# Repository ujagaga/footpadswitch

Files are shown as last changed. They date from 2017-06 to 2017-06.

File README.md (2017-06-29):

# footpadswitch
Foot pad configurable shortcut key

The intention is to build a radio frequency foot switch to activate a usb device 
which acts as a HID keyboard sending an alt/F12 key code. This can be caught by an 
application which can be configured for various tasks.
I used an RF transmit module for the foot pad controller and RF receive module for
activating a microcontroller to send the key code.
The microcontroller is AtTiny2313 and the firmware is baces on AVR USB library.

The RF receiver gets a lot of noise, so I filtered it out with an RC low pass filter.
Because of this, the controlling signal must last at least 10ms.   

I wrote the application in python, built it into a standalone windows application using py2exe
and created an installer using CreateInstall. You should start the app as an administrator to 
allow writing the config file or install somewhere you have write priviledges like user 
application folder. Once you start the app, it saves current mouse position after you press 
ctrl/F12 and uses it as location to simulate a click when it receives alt/F12. This basically 
gives you the option to generate a mouse click on a configured place on the screen. I use it 
for an application which has no keyboard shortcuts and my hands are busy, so I can not click myself.

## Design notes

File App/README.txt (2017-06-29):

Footpad Switch

The application is intended to be used with a hardware radio frequency foot switch to activate 
a usb device which acts as a HID keyboard sending an alt/F12 key code. 
If you install the app in Program Files folder, you should start the app as an administrator to 
allow writing the config file or install somewhere you have write priviledges.
Once you start the app, it saves current mouse position after you press ctrl/F12 and uses it as 
location to simulate a click after detecting alt/F12. This means that to configure a place on the
screen where to simulate mouse click, place your mouse cursor and hit ctrl/F12. After that, 
to simulate mouse click, just press the footpad which will send alt/F12.

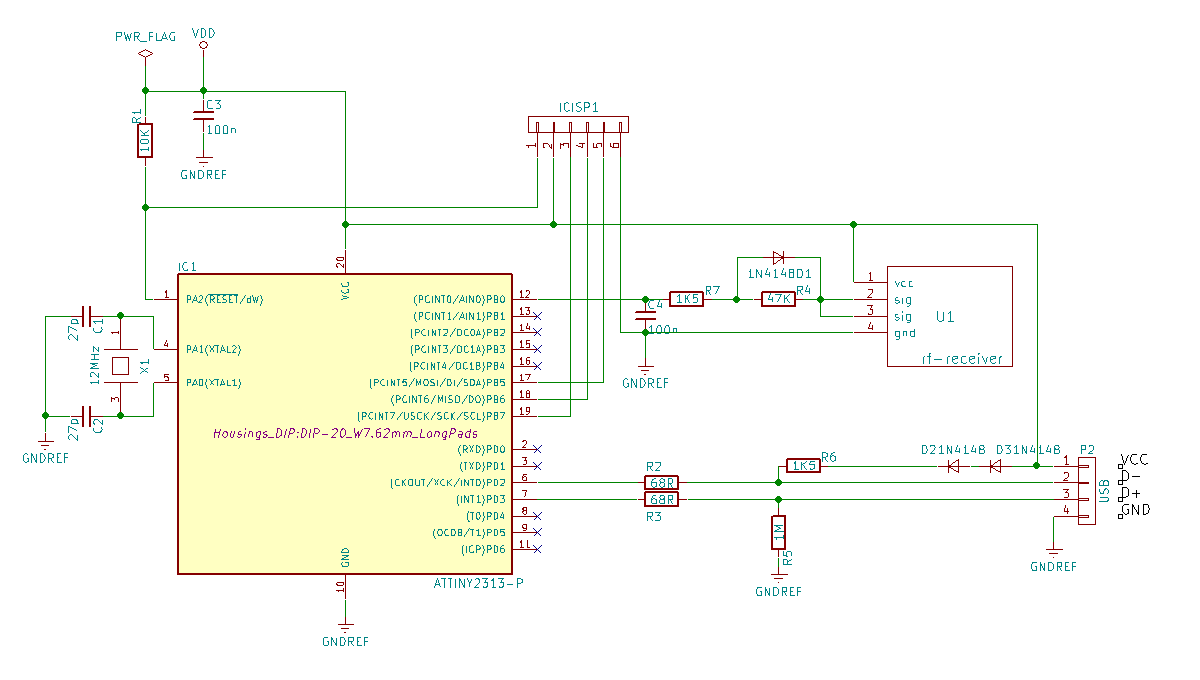
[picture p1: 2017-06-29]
PCB/wififp_receiver/SCHEMATIC.png

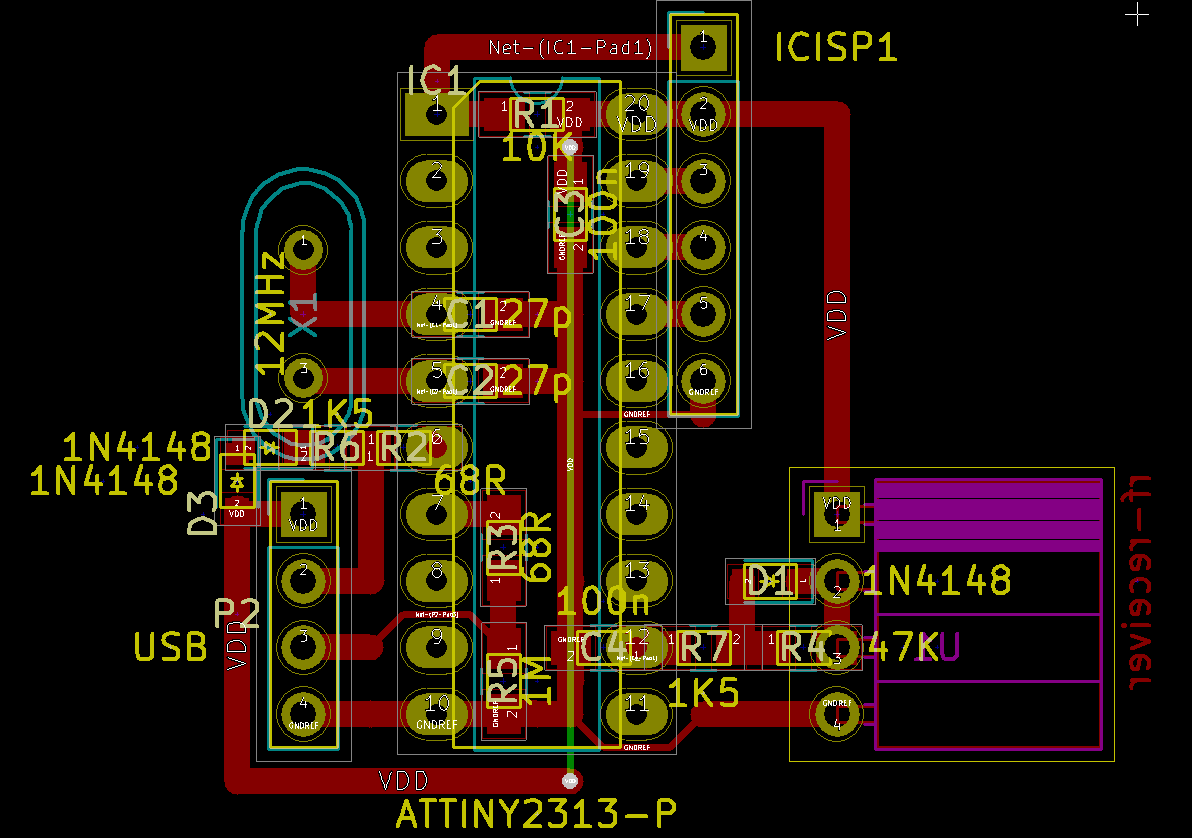
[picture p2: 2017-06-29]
PCB/wififp_receiver/PCB.png

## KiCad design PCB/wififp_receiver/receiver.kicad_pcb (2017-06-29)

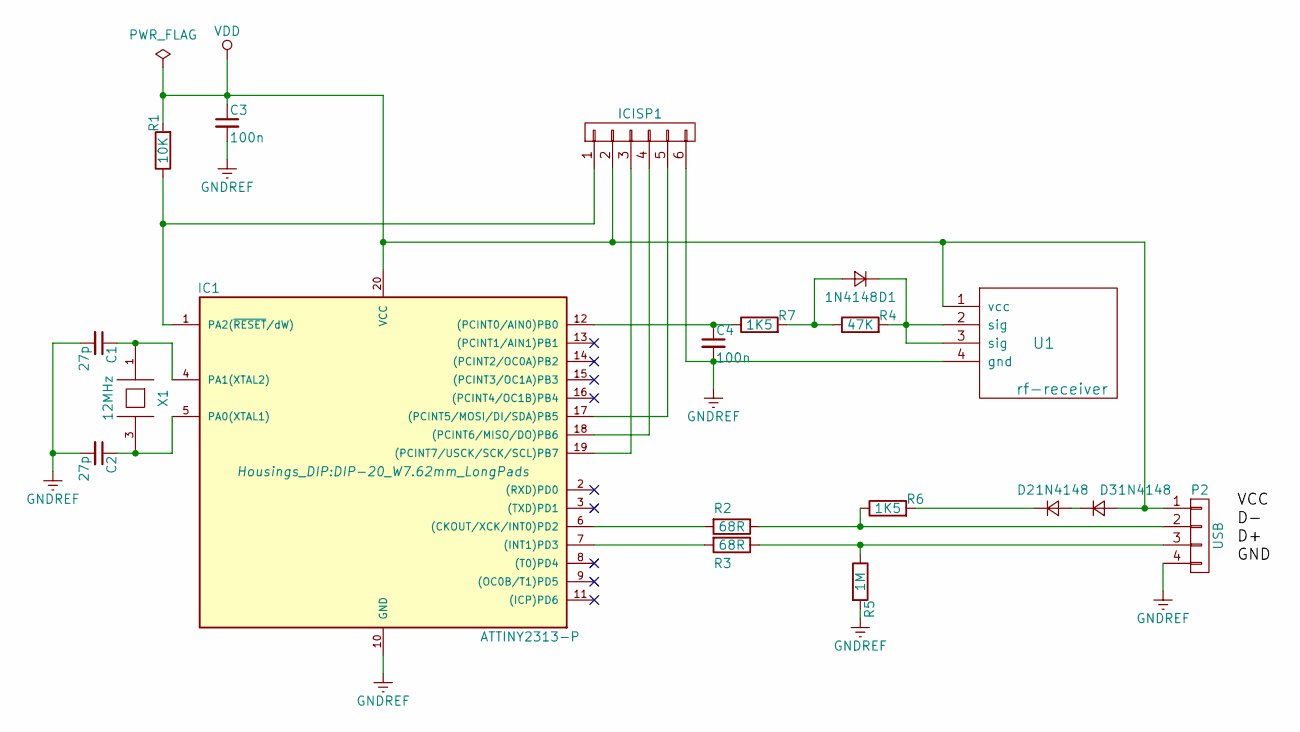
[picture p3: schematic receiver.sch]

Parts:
C1, C2: 27p; C_0805_HandSoldering
C3, C4: 100n; C_0805_HandSoldering
D1, D2, D3: 1N4148; D_0805
IC1: ATTINY2313-P; DIP-20_W7.62mm_LongPads
P1: ICISP1; Socket_Strip_Straight_1x06_Pitch2.54mm
P2: USB; Socket_Strip_Straight_1x04_Pitch2.54mm
R1: 10K; C_0805_HandSoldering
R2, R3: 68R; C_0805_HandSoldering
R4: 47K; C_0805_HandSoldering
R5: 1M; C_0805_HandSoldering
R6, R7: 1K5; C_0805_HandSoldering
U1: rf-receiver; Socket_Strip_Angled_1x04_Pitch2.54mm
X1: 12MHz; Crystal_HC49-U_Vertical

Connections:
GNDREF: C1.2, C2.2, C3.2, C4.2, IC1.10 (GND), P1.6, P2.4, R5.2, U1.4 (gnd)
unnamed: C1.1, IC1.4 (PA1(XTAL2)), X1.1
unnamed: C2.1, IC1.5 (PA0(XTAL1)), X1.3
unnamed: C4.1, IC1.12 ((PCINT0/AIN0)PB0), R7.1
unnamed: D1.1 (K), R4.2, U1.2 (sig), U1.3 (sig)
unnamed: D1.2 (A), R4.1, R7.2
unnamed: D2.1 (K), R6.2
unnamed: D2.2 (A), D3.1 (K)
unnamed: IC1.1 (PA2(~RESET~/dW)), P1.1, R1.1
unnamed: IC1.6 ((CKOUT/XCK/INT0)PD2), R2.2
unnamed: IC1.7 ((INT1)PD3), R3.2
unnamed: IC1.17 ((PCINT5/MOSI/DI/SDA)PB5), P1.5
unnamed: IC1.18 ((PCINT6/MISO/DO)PB6), P1.4
unnamed: IC1.19 ((PCINT7/USCK/SCK/SCL)PB7), P1.3
unnamed: P2.2, R2.1, R6.1
unnamed: P2.3, R3.1, R5.1
VDD: C3.1, D3.2 (A), IC1.20 (VCC), P1.2, P2.1, R1.2, U1.1 (vcc)

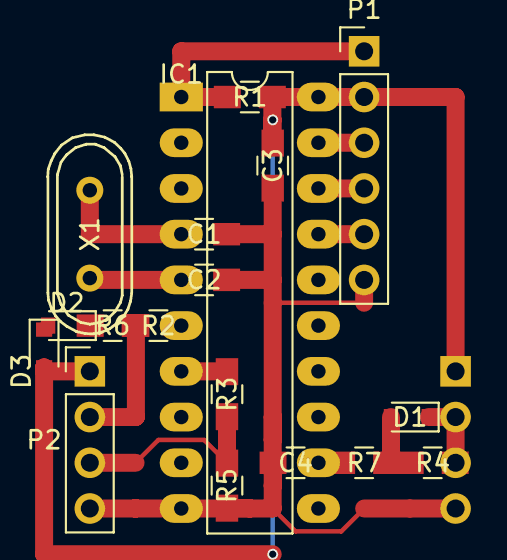
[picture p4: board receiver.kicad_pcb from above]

Board: 2 copper layers, 19 parts (1 on the bottom side), 17 nets.

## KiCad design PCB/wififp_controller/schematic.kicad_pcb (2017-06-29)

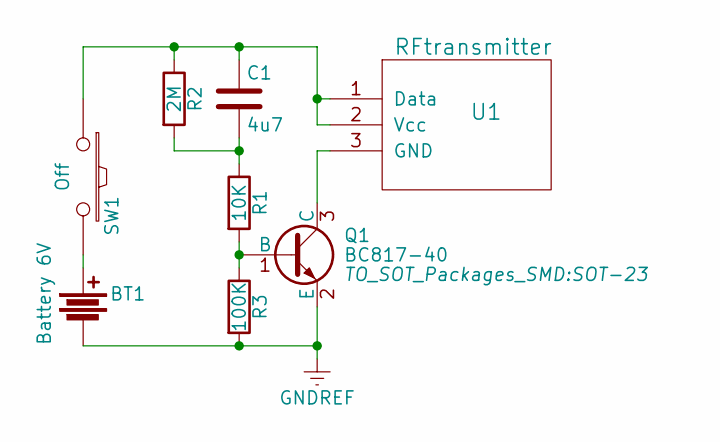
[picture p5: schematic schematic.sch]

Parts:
BT1: Battery 6V; 6V_battery_4LR44
C1: 4u7; C_0805_HandSoldering
Q1: BC817-40; SOT-23
R1: 10K; R_0805_HandSoldering
R2: 2M; R_0805_HandSoldering
R3: 100K; R_0805_HandSoldering
SW1: Off; Socket_Strip_Straight_1x02_Pitch2.54mm
U1: RFtransmitter; Socket_Strip_Angled_1x03_Pitch2.54mm

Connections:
GNDREF: BT1.2, Q1.2 (E), R3.2
unnamed: BT1.1, SW1.2
unnamed: C1.1, R2.1, SW1.1, U1.1 (Data), U1.2 (Vcc)
unnamed: C1.2, R1.1, R2.2
unnamed: Q1.1 (B), R1.2, R3.1
unnamed: Q1.3 (C), U1.3 (GND)

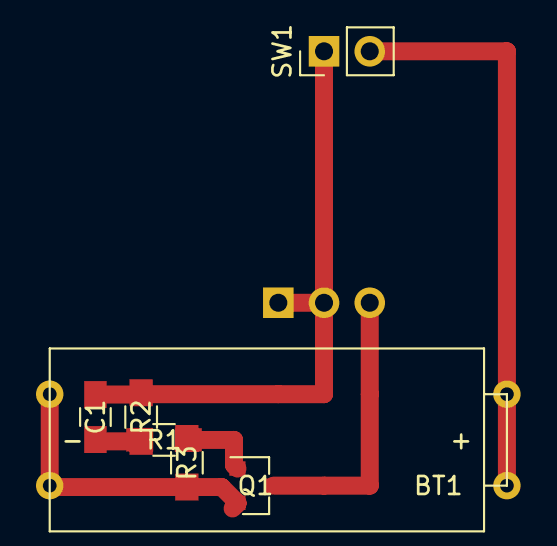
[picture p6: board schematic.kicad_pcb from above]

Board: 2 copper layers, 8 parts (1 on the bottom side), 6 nets.

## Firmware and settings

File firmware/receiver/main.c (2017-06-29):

/* Name: main.c
 * Project: hid-mouse, a very simple HID example
 * Author: Christian Starkjohann
 * Creation Date: 2008-04-07
 * Tabsize: 4
 * Copyright: (c) 2008 by OBJECTIVE DEVELOPMENT Software GmbH
 * License: GNU GPL v2 (see License.txt), GNU GPL v3 or proprietary (CommercialLicense.txt)
 */

/*
This example should run on most AVRs with only little changes. No special
hardware resources except INT0 are used. You may have to change usbconfig.h for
different I/O pins for USB. Please note that USB D+ must be the INT0 pin, or
at least be connected to INT0 as well.

We use VID/PID 0x046D/0xC00E which is taken from a Logitech mouse. Don't
publish any hardware using these IDs! This is for demonstration only!
*/

#include <avr/io.h>
#include <avr/wdt.h>
#include <avr/interrupt.h>  /* for sei() */
#include <avr/pgmspace.h>   /* required by usbdrv.h */
#include <util/delay.h>     /* for _delay_ms() */
#include <stdint.h>
#include <stdbool.h>
#include "usbdrv/usbdrv.h"

/* ------------------------------------------------------------------------- */

#define SENS_PIN			(PB0)
#define GET_STATE()			((PINB >> SENS_PIN) & 1U)
#define SENS_THREASHOLD		(10000U)

/* ----------------------------- USB interface ----------------------------- */

/* Keyboard usage values, see usb.org's HID-usage-tables document, chapter
 * 10 Keyboard/Keypad Page for more codes.
 */
#define MOD_CONTROL_LEFT    (1<<0)
#define MOD_SHIFT_LEFT      (1<<1)
#define MOD_ALT_LEFT        (1<<2)
#define MOD_GUI_LEFT        (1<<3)
#define MOD_CONTROL_RIGHT   (1<<4)
#define MOD_SHIFT_RIGHT     (1<<5)
#define MOD_ALT_RIGHT       (1<<6)
#define MOD_GUI_RIGHT       (1<<7)

#define KEY_A       4
#define KEY_B       5
#define KEY_C       6
#define KEY_D       7
#define KEY_E       8
#define KEY_F       9
#define KEY_G       10
#define KEY_H       11
#define KEY_I       12
#define KEY_J       13
#define KEY_K       14
#define KEY_L       15
#define KEY_M       16
#define KEY_N       17
#define KEY_O       18
#define KEY_P       19
#define KEY_Q       20
#define KEY_R       21
#define KEY_S       22
#define KEY_T       23
#define KEY_U       24
#define KEY_V       25
#define KEY_W       26
#define KEY_X       27
#define KEY_Y       28
#define KEY_Z       29
#define KEY_1       30
#define KEY_2       31
#define KEY_3       32
#define KEY_4       33
#define KEY_5       34
#define KEY_6       35
#define KEY_7       36
#define KEY_8       37
#define KEY_9       38
#define KEY_0       39

#define KEY_F1      58
#define KEY_F2      59
#define KEY_F3      60
#define KEY_F4      61
#define KEY_F5      62
#define KEY_F6      63
#define KEY_F7      64
#define KEY_F8      65
#define KEY_F9      66
#define KEY_F10     67
#define KEY_F11     68
#define KEY_F12     69
#define KEY_F13     70
#define KEY_F14     71
#define KEY_F15     72
#define KEY_F16     73

/* ------------------------------------------------------------------------ */

/* ------------------------------------------------------------------------- */

static uchar    pressKeyBuffer[2] = {MOD_ALT_LEFT, KEY_F12};    /* buffer for HID reports */
static uchar    releaseKeyBuffer[2] = {0, 0};    /* buffer for HID reports */
static uchar    idleRate;           /* in 4 ms units */

const PROGMEM char usbHidReportDescriptor[35] = {   /* USB report descriptor */
    0x05, 0x01,                    // USAGE_PAGE (Generic Desktop)
    0x09, 0x06,                    // USAGE (Keyboard)
    0xa1, 0x01,                    // COLLECTION (Application)
    0x05, 0x07,                    //   USAGE_PAGE (Keyboard)
    0x19, 0xe0,                    //   USAGE_MINIMUM (Keyboard LeftControl)
    0x29, 0xe7,                    //   USAGE_MAXIMUM (Keyboard Right GUI)
    0x15, 0x00,                    //   LOGICAL_MINIMUM (0)
    0x25, 0x01,                    //   LOGICAL_MAXIMUM (1)
    0x75, 0x01,                    //   REPORT_SIZE (1)
    0x95, 0x08,                    //   REPORT_COUNT (8)
    0x81, 0x02,                    //   INPUT (Data,Var,Abs)
    0x95, 0x01,                    //   REPORT_COUNT (1)
    0x75, 0x08,                    //   REPORT_SIZE (8)
    0x25, 0x65,                    //   LOGICAL_MAXIMUM (101)
    0x19, 0x00,                    //   USAGE_MINIMUM (Reserved (no event indicated))
    0x29, 0x65,                    //   USAGE_MAXIMUM (Keyboard Application)
    0x81, 0x00,                    //   INPUT (Data,Ary,Abs)
    0xc0                           // END_COLLECTION
};
/* We use a simplifed keyboard report descriptor which does not support the
 * boot protocol. We don't allow setting status LEDs and we only allow one
 * simultaneous key press (except modifiers). We can therefore use short
 * 2 byte input reports.
 * The report descriptor has been created with usb.org's "HID Descriptor Tool"
 * which can be downloaded from http://www.usb.org/developers/hidpage/.
 * Redundant entries (such as LOGICAL_MINIMUM and USAGE_PAGE) have been omitted
 * for the second INPUT item.
 */

usbMsgLen_t usbFunctionSetup(uchar data[8]){

	usbRequest_t    *rq = (void *)data;

	    usbMsgPtr = pressKeyBuffer;
	    if((rq->bmRequestType & USBRQ_TYPE_MASK) == USBRQ_TYPE_CLASS){    /* class request type */
	        if(rq->bRequest == USBRQ_HID_GET_REPORT){  /* wValue: ReportType (highbyte), ReportID (lowbyte) */
	            /* we only have one report type, so don't look at wValue */
	            return sizeof(pressKeyBuffer);
	        }else if(rq->bRequest == USBRQ_HID_GET_IDLE){
	            usbMsgPtr = &idleRate;
	            return 1;
	        }else if(rq->bRequest == USBRQ_HID_SET_IDLE){
	            idleRate = rq->wValue.bytes[1];
	        }
	    }else{
	        /* no vendor specific requests implemented */
	    }
		return 0;
}


void sendKey( void ){
	bool finished = false;
	bool keySent = false;

	while(!finished){
		wdt_reset();
		usbPoll();

		if(usbInterruptIsReady()){
			if(!keySent){
				usbSetInterrupt(pressKeyBuffer, sizeof(pressKeyBuffer));
				keySent = true;
			}else{
				usbSetInterrupt(releaseKeyBuffer, sizeof(releaseKeyBuffer));
				finished = true;
			}
		}
	}
}

void delayLoop( void ){
	volatile uint8_t i;

	for(i = 0; i < 200; i++){

		wdt_reset();
		usbPoll();

		_delay_ms(5);
	}
}


int main(void)
{
	uint16_t i = 0;

    wdt_enable(WDTO_2S);
    /* If you don't use the watchdog, replace the call above with a wdt_disable().
     * On newer devices, the status of the watchdog (on/off, period) is PRESERVED
     * OVER RESET!
     */
    /* RESET status: all port bits are inputs without pull-up.
     * That's the way we need D+ and D-. Therefore we don't need any
     * additional hardware initialization.
     */
    usbInit();
    usbDeviceDisconnect();  /* enforce re-enumeration, do this while interrupts are disabled! */

    i = 255;
    while(--i){             /* fake USB disconnect for > 250 ms */
        wdt_reset();
        _delay_ms(1);
    }
    usbDeviceConnect();
    sei();

    for(;;){                /* main event loop */
        wdt_reset();
        usbPoll();

        if(GET_STATE()){	/* test if command requested */
        	i++;
        }else{
        	i = 0;
        }

        if( i == SENS_THREASHOLD){
        	sendKey();
        	i = 0;
        	delayLoop();
        }
    }

    return 0;
}

/* ------------------------------------------------------------------------- */

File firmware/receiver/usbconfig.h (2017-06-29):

/* Name: usbconfig.h
 * Project: V-USB, virtual USB port for Atmel's(r) AVR(r) microcontrollers
 * Author: Christian Starkjohann
 * Creation Date: 2005-04-01
 * Tabsize: 4
 * Copyright: (c) 2005 by OBJECTIVE DEVELOPMENT Software GmbH
 * License: GNU GPL v2 (see License.txt), GNU GPL v3 or proprietary (CommercialLicense.txt)
 */

#ifndef __usbconfig_h_included__
#define __usbconfig_h_included__

/*
General Description:
This file is an example configuration (with inline documentation) for the USB
driver. It configures V-USB for USB D+ connected to Port D bit 2 (which is
also hardware interrupt 0 on many devices) and USB D- to Port D bit 4. You may
wire the lines to any other port, as long as D+ is also wired to INT0 (or any
other hardware interrupt, as long as it is the highest level interrupt, see
section at the end of this file).
+ To create your own usbconfig.h file, copy this file to your project's
+ firmware source directory) and rename it to "usbconfig.h".
+ Then edit it accordingly.
*/

/* ---------------------------- Hardware Config ---------------------------- */

#define USB_CFG_IOPORTNAME      D
/* This is the port where the USB bus is connected. When you configure it to
 * "B", the registers PORTB, PINB and DDRB will be used.
 */
#define USB_CFG_DMINUS_BIT      2
/* This is the bit number in USB_CFG_IOPORT where the USB D- line is connected.
 * This may be any bit in the port.
 */
#define USB_CFG_DPLUS_BIT       3
/* This is the bit number in USB_CFG_IOPORT where the USB D+ line is connected.
 * This may be any bit in the port. Please note that D+ must also be connected
 * to interrupt pin INT0! [You can also use other interrupts, see section
 * "Optional MCU Description" below, or you can connect D- to the interrupt, as
 * it is required if you use the USB_COUNT_SOF feature. If you use D- for the
 * interrupt, the USB interrupt will also be triggered at Start-Of-Frame
 * markers every millisecond.]
 */
#define USB_CFG_CLOCK_KHZ       (12000)
/* Clock rate of the AVR in kHz. Legal values are 12000, 12800, 15000, 16000,
 * 16500, 18000 and 20000. The 12.8 MHz and 16.5 MHz versions of the code
 * require no crystal, they tolerate +/- 1% deviation from the nominal
 * frequency. All other rates require a precision of 2000 ppm and thus a
 * crystal!
 * Since F_CPU should be defined to your actual clock rate anyway, you should
 * not need to modify this setting.
 */
#define USB_CFG_CHECK_CRC       0
/* Define this to 1 if you want that the driver checks integrity of incoming
 * data packets (CRC checks). CRC checks cost quite a bit of code size and are
 * currently only available for 18 MHz crystal clock. You must choose
 * USB_CFG_CLOCK_KHZ = 18000 if you enable this option.
 */

/* ----------------------- Optional Hardware Config ------------------------ */

/* #define USB_CFG_PULLUP_IOPORTNAME   D */
/* If you connect the 1.5k pullup resistor from D- to a port pin instead of
 * V+, you can connect and disconnect the device from firmware by calling
 * the macros usbDeviceConnect() and usbDeviceDisconnect() (see usbdrv.h).
 * This constant defines the port on which the pullup resistor is connected.
 */
/* #define USB_CFG_PULLUP_BIT          4 */
/* This constant defines the bit number in USB_CFG_PULLUP_IOPORT (defined
 * above) where the 1.5k pullup resistor is connected. See description
 * above for details.
 */

/* --------------------------- Functional Range ---------------------------- */
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

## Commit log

2017-06-29 All finished and working
    [config.txt, receiver.kicad_pcb, receiver.sch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]
2017-06-29 Updated the schematic
    [receiver.kicad_pcb, receiver.sch]
